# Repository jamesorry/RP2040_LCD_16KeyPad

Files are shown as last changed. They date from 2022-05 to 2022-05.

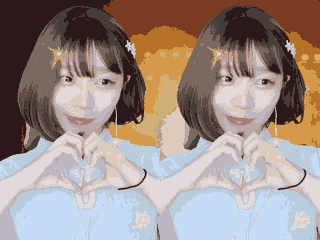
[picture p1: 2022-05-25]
firmware/images/697478.bmp

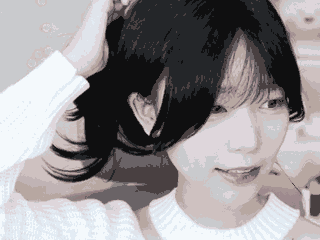
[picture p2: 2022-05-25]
firmware/images/LINE_ALBUM_2022517_220517_4.bmp

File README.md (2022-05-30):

# [RP2040_LCD_16KeyPad](https://hackmd.io/@Jub9Bu1BR0qRYeSAA0wUJQ/RP2040_LCD_16KeyPad)



## 元件
* 16 x Cherry MX 1u
* 16 x 1N4148 diodes
* 16 x RGB LEDs SK6812MINI-E([datasheet](https://www.google.com/url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))
* 1 x RP2040-zero([wiki](https://www.waveshare.net/wiki/RP2040-Zero))
* 1 x 2.4inch SPI ili9341 LCD module([wiki](http://www.lcdwiki.com/zh/2.4inch_SPI_Module_ILI9341_SKU:MSP2402))
* 1 x Rotary encoder switch

## Circuitpython 環境設定
### [官方教學文件](https://learn.adafruit.com/circuitpython-essentials)
### [API Reference](https://docs.circuitpython.org/en/latest/docs/index.html)
### [Library Bundle](https://github.com/adafruit/Adafruit_CircuitPython_Bundle/releases)
### [Community Library Bundle](https://github.com/adafruit/CircuitPython_Community_Bundle/releases)
### 燒綠官方韌體
1. [下載UF2](https://circuitpython.org/board/raspberry_pi_pico/)


2. 將板子按住BOOT键後連接電腦，鬆開BOOT鍵，電腦會出現一個新的磁碟空間，將下載的.uf2檔案複製進去即可完成燒錄。
### Thonny IDE
[官網下載](https://thonny.org/)
1. 下载Thonny IDE Windows版 並依照步驟安裝
2. 安裝完成後，第一次要配置語言和主板環境，為了使用Pico，所以注意主板環境選擇Raspberry Pi 選項。
3. 完成後，修改編譯環境，選擇CircuitPython，若已經接上設備，則可選擇連結埠



1. 點擊OK回到Thonny主界面，然后點擊停止按鈕，在Shell中即可顯示當前使用到的環境

以上都有出現即完成安裝設定

### 執行
將firmware資料夾的所有檔案複製進板子的磁碟空間內，完成後將板子重新啟動則可使用

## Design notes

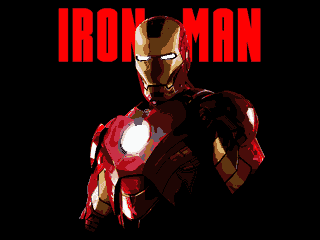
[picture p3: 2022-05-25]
firmware/images/_21_black-iron-man-wallpaper_Wallpaper-Iron-Man,-Artwork,-Minimal,-Low-poly,-Dark-.bmp

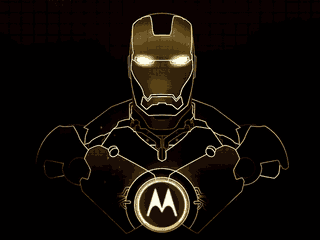
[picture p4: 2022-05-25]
firmware/images/_21_black-iron-man-wallpaper_Iron-Man-Wallpapers-Top-Free-Iron-Man-Backgrounds-.bmp

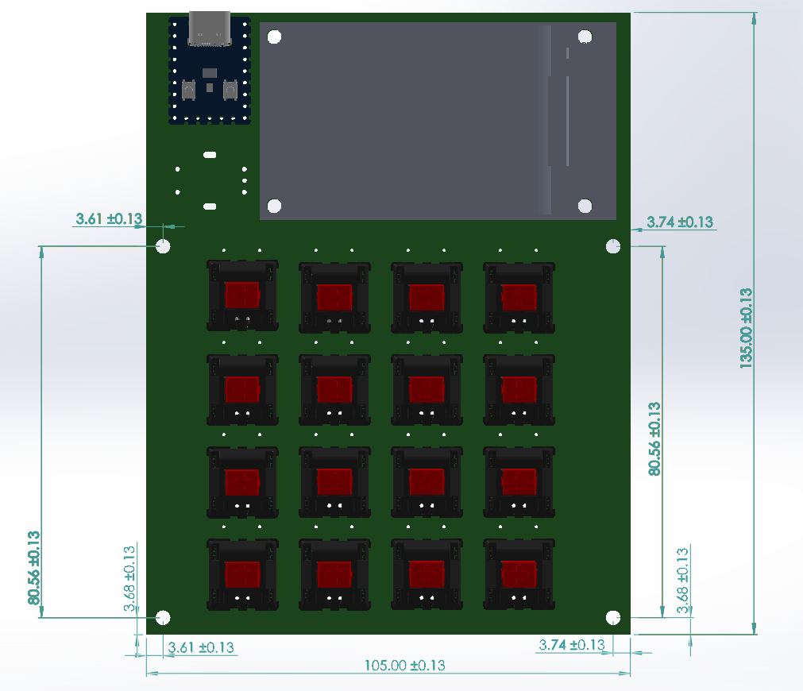
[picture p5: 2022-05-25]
PCB-design/Snipaste_2022-05-17_00-06-32.png

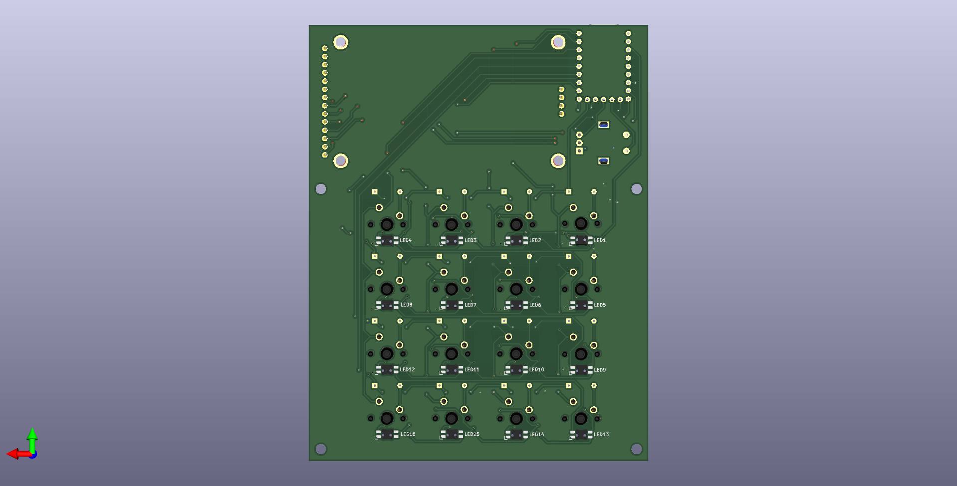
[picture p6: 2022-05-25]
images/RP2040_16Key_ili9341_LCD_keypad_back.png

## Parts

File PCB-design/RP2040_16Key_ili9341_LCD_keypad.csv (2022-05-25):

Source: | C:\Users\james\Desktop\LAB357\Raspberry Pi Pico\Pi Pico KeyPad\Pi Pico RP2040 keypad\RP2040_16Key_ili9341_LCD_keypad\RP2040_16Key_ili9341_LCD_keypad.kicad_sch
Date: | 2022/5/18
Tool: | Eeschema (6.0.4)
Generator: | C:\Program Files\KiCad\6.0\bin\scripting\plugins/bom_csv_grouped_by_value.py
Component Count: | 51
Individual Components:
Item | Qty | Reference(s) | Value | LibPart | Footprint | Datasheet
 |  | D1 | D | Device:D | keyboard_parts:D_SOD123_axial | ~
 |  | D2 | D | Device:D | keyboard_parts:D_SOD123_axial | ~
 |  | D3 | D | Device:D | keyboard_parts:D_SOD123_axial | ~
 |  | D4 | D | Device:D | keyboard_parts:D_SOD123_axial | ~
 |  | D5 | D | Device:D | keyboard_parts:D_SOD123_axial | ~
 |  | D6 | D | Device:D | keyboard_parts:D_SOD123_axial | ~
 |  | D7 | D | Device:D | keyboard_parts:D_SOD123_axial | ~
 |  | D8 | D | Device:D | keyboard_parts:D_SOD123_axial | ~
 |  | D9 | D | Device:D | keyboard_parts:D_SOD123_axial | ~
 |  | D10 | D | Device:D | keyboard_parts:D_SOD123_axial | ~
 |  | D11 | D | Device:D | keyboard_parts:D_SOD123_axial | ~
 |  | D12 | D | Device:D | keyboard_parts:D_SOD123_axial | ~
 |  | D13 | D | Device:D | keyboard_parts:D_SOD123_axial | ~
 |  | D14 | D | Device:D | keyboard_parts:D_SOD123_axial | ~
 |  | D15 | D | Device:D | keyboard_parts:D_SOD123_axial | ~
 |  | D16 | D | Device:D | keyboard_parts:D_SOD123_axial | ~
 |  | K1 | KEYSW | keyboard_parts:KEYSW | Button_Switch_Keyboard:SW_Cherry_MX_1.00u_PCB
 |  | K2 | KEYSW | keyboard_parts:KEYSW | Button_Switch_Keyboard:SW_Cherry_MX_1.00u_PCB
 |  | K3 | KEYSW | keyboard_parts:KEYSW | Button_Switch_Keyboard:SW_Cherry_MX_1.00u_PCB
 |  | K4 | KEYSW | keyboard_parts:KEYSW | Button_Switch_Keyboard:SW_Cherry_MX_1.00u_PCB
 |  | K5 | KEYSW | keyboard_parts:KEYSW | Button_Switch_Keyboard:SW_Cherry_MX_1.00u_PCB
 |  | K6 | KEYSW | keyboard_parts:KEYSW | Button_Switch_Keyboard:SW_Cherry_MX_1.00u_PCB
 |  | K7 | KEYSW | keyboard_parts:KEYSW | Button_Switch_Keyboard:SW_Cherry_MX_1.00u_PCB
 |  | K8 | KEYSW | keyboard_parts:KEYSW | Button_Switch_Keyboard:SW_Cherry_MX_1.00u_PCB
 |  | K9 | KEYSW | keyboard_parts:KEYSW | Button_Switch_Keyboard:SW_Cherry_MX_1.00u_PCB
 |  | K10 | KEYSW | keyboard_parts:KEYSW | Button_Switch_Keyboard:SW_Cherry_MX_1.00u_PCB
 |  | K11 | KEYSW | keyboard_parts:KEYSW | Button_Switch_Keyboard:SW_Cherry_MX_1.00u_PCB
 |  | K12 | KEYSW | keyboard_parts:KEYSW | Button_Switch_Keyboard:SW_Cherry_MX_1.00u_PCB
 |  | K13 | KEYSW | keyboard_parts:KEYSW | Button_Switch_Keyboard:SW_Cherry_MX_1.00u_PCB
 |  | K14 | KEYSW | keyboard_parts:KEYSW | Button_Switch_Keyboard:SW_Cherry_MX_1.00u_PCB
 |  | K15 | KEYSW | keyboard_parts:KEYSW | Button_Switch_Keyboard:SW_Cherry_MX_1.00u_PCB
 |  | K16 | KEYSW | keyboard_parts:KEYSW | Button_Switch_Keyboard:SW_Cherry_MX_1.00u_PCB
 |  | LED1 | MX_SK6812MINI-E | :MX_SK6812MINI-E_1 | marbastlib-mx:LED_MX_6028R
 |  | LED2 | MX_SK6812MINI-E | :MX_SK6812MINI-E_2 | marbastlib-mx:LED_MX_6028R
 |  | LED3 | MX_SK6812MINI-E | :MX_SK6812MINI-E_3 | marbastlib-mx:LED_MX_6028R
 |  | LED4 | MX_SK6812MINI-E | :MX_SK6812MINI-E_4 | marbastlib-mx:LED_MX_6028R
 |  | LED5 | MX_SK6812MINI-E | :MX_SK6812MINI-E_5 | marbastlib-mx:LED_MX_6028R
 |  | LED6 | MX_SK6812MINI-E | :MX_SK6812MINI-E_6 | marbastlib-mx:LED_MX_6028R
 |  | LED7 | MX_SK6812MINI-E | :MX_SK6812MINI-E_7 | marbastlib-mx:LED_MX_6028R
 |  | LED8 | MX_SK6812MINI-E | :MX_SK6812MINI-E_8 | marbastlib-mx:LED_MX_6028R
 |  | LED9 | MX_SK6812MINI-E | :MX_SK6812MINI-E_9 | marbastlib-mx:LED_MX_6028R
 |  | LED10 | MX_SK6812MINI-E | :MX_SK6812MINI-E_10 | marbastlib-mx:LED_MX_6028R
 |  | LED11 | MX_SK6812MINI-E | :MX_SK6812MINI-E_11 | marbastlib-mx:LED_MX_6028R
 |  | LED12 | MX_SK6812MINI-E | :MX_SK6812MINI-E_12 | marbastlib-mx:LED_MX_6028R
 |  | LED13 | MX_SK6812MINI-E | :MX_SK6812MINI-E_13 | marbastlib-mx:LED_MX_6028R
 |  | LED14 | MX_SK6812MINI-E | :MX_SK6812MINI-E_14 | marbastlib-mx:LED_MX_6028R
 |  | LED15 | MX_SK6812MINI-E | :MX_SK6812MINI-E_15 | marbastlib-mx:LED_MX_6028R
 |  | LED16 | MX_SK6812MINI-E | marbastlib-mx:MX_SK6812MINI-E | marbastlib-mx:LED_MX_6028R
 |  | RZ1 | RP2040-Zero | rp2040-zero:RP2040-Zero | RP2040-Zero:RP2040-Zero
 |  | SW1 | RotaryEncoder_Switch | Device:RotaryEncoder_Switch | Keebio-Parts:RotaryEncoder_Alps_EC11E-Switch_Vertical_H20mm | ~
 |  | U1 | 2.4_TFT_SPI_240x320 | 2.4inch_ili9341:2.4_TFT_SPI_240x320 | 2.4inch_ili9341:2.4_TFT_SPI_240x320 | http://www.lcdwiki.com/zh/2.4inch_SPI_Module_ILI9341_SKU:MSP2402

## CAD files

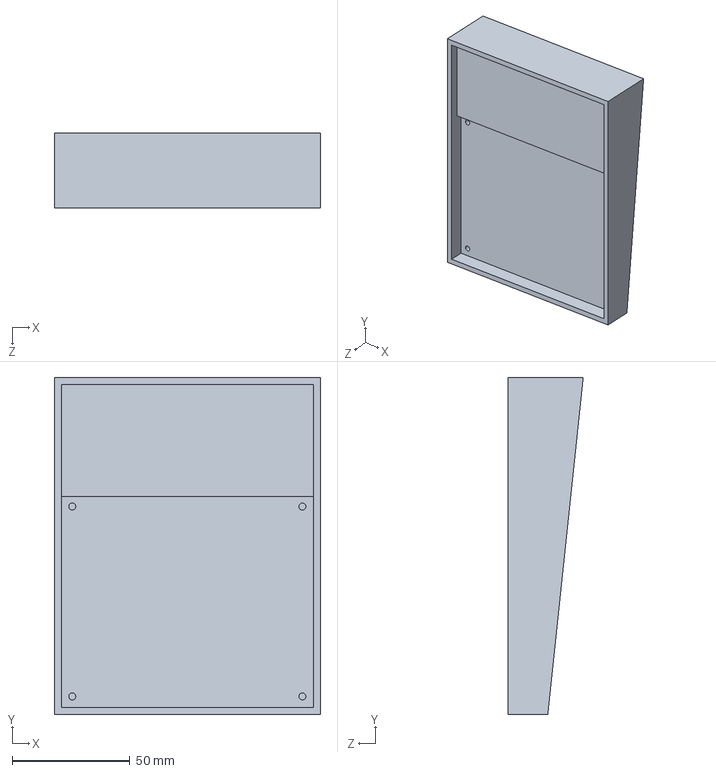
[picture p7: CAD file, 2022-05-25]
3DP-Bottom_Holder/Bottom_Holder.SLDPRT
113.0 x 143.0 x 32.0 mm

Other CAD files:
3DP-Bottom_Holder/Bottom_Holder.STL

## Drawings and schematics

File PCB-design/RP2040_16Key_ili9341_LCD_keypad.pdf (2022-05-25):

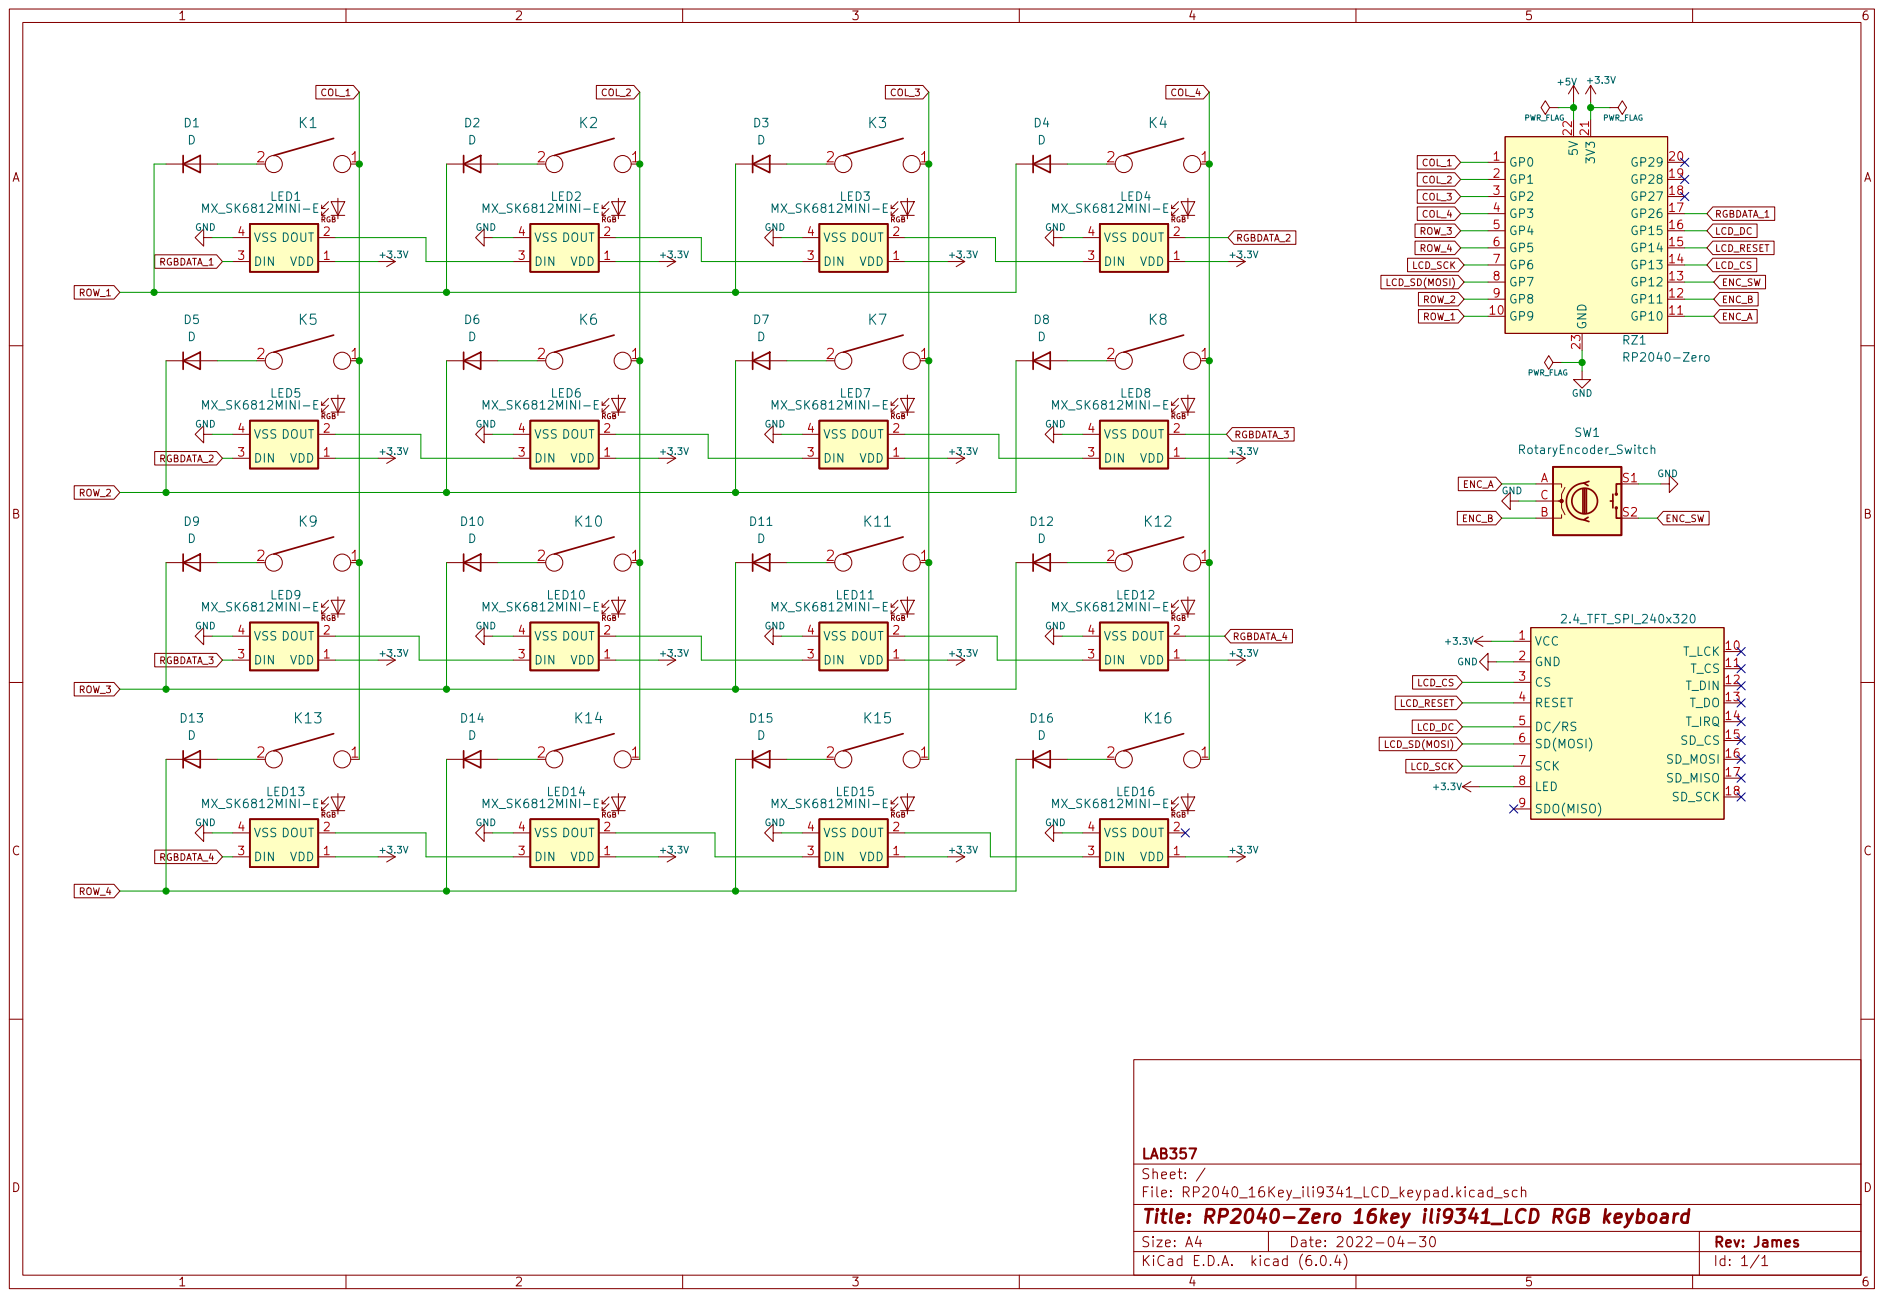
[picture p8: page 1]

Id: 1/1 Title: RP2040-Zero 16key ili9341_LCD RGB keyboard

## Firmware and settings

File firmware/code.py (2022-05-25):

import os
import time
import displayio
import terminalio
from adafruit_display_shapes.rect import Rect
from adafruit_display_text import label
from myMacroPad import MacroPad
import gc
import random
import adafruit_imageload

displayio.release_displays()
def DEBUG_STRING(string):
    pass
#     print(string)
def DEBUG_STRING_INFO(string, value):
    pass
#     print(string, value)
    
# CONFIGURABLES ------------------------

MACRO_FOLDER = '/macros'
KEY_TOTAL = 16
IMAGE_FOLDER = "/images"
change_press_RGB = True #when press btn change rgb color
now_RGB_animation_num = -1
start_picture_show = False #進入更新圖片迴圈(無法做其他事情)
break_flag = True #用來中斷迴圈
show_Information = False #進到此畫面
list_infomation = ['Version: 0.1.2',
                   'CircuitPython 7.2.5',
                   'RP2040-Zero',
                   '16key_SPI_ili9341_LCD',
                   '@James Lu']
# CLASSES AND FUNCTIONS ----------------
class App:
    """ Class representing a host-side application, for which we have a set
        of macro sequences. Project code was originally more complex and
        this was helpful, but maybe it's excessive now?"""
    def __init__(self, appdata):
        self.name = appdata['name']
        self.macros = appdata['macros']

    def switch(self):
        """ Activate application settings; update OLED labels and LED
            colors. """
        group[KEY_TOTAL + 1].text = self.name   # Application name
        DEBUG_STRING_INFO("self.name:", str(self.name))
        for i in range(KEY_TOTAL):
            if i < len(self.macros): # Key in use, set label + LED color
                if change_press_RGB:
                    macropad.pixels[i] = self.macros[i][0]
                group[i].text = self.macros[i][1]
            else:  # Key not in use, no label or LED
                if change_press_RGB:
                    macropad.pixels[i] = 0
                group[i].text = ''
        if self.name == "RGB Config":
            group[3].text = str(round(macropad.pixels.brightness,1))
            group[11].text = str(now_RGB_animation_num)
        macropad.keyboard.release_all()
        macropad.consumer_control.release()
        macropad.mouse.release_all()
        #if not macropad.animations.animate():
        if change_press_RGB:
            DEBUG_STRING("-----PAGE RGB-----")
            macropad.pixels.show()
        gc.collect()


# INITIALIZATION -----------------------

macropad = MacroPad()
macropad.pixels.auto_write = False
macropad.pixels.brightness = 0.1

# Set up displayio group with all the labels
group = displayio.Group()
DEBUG_STRING_INFO("width:", str(macropad.display.width))
DEBUG_STRING_INFO("height:", str(macropad.display.height))

for key_index in range(KEY_TOTAL):
    x = key_index % 4
    y = key_index // 4
    group.append(label.Label(terminalio.FONT, text='', color=0xFFFFFF,scale=2,
                             anchored_position=((macropad.display.width - 1) * x / 3,
                                                40+(macropad.display.height//5*(y+1))),
                             anchor_point=(x / 3, 1.0)))
    
group.append(Rect(0, 0, macropad.display.width, 40, fill=0xFFFFFF))
group.append(label.Label(terminalio.FONT, text='', color=0x000000,
                         scale=3,
                         anchored_position=(macropad.display.width / 2, -4),
                         anchor_point=(0.5, 0.0)))
macropad.display.show(group)

DEBUG_STRING_INFO("free mem@after bitmap", gc.mem_free())
gc.collect()
DEBUG_STRING_INFO("free mem@after gc.collect()", gc.mem_free())

# Load all the macro key setups from .py files in MACRO_FOLDER
apps = []
files = os.listdir(MACRO_FOLDER)
files.sort()
for filename in files:
    if filename.endswith('.py') and not filename.startswith('._'):
        try:
            module = __import__(MACRO_FOLDER + '/' + filename[:-3])
            apps.append(App(module.app))
        except (SyntaxError, ImportError, AttributeError, KeyError, NameError,
                IndexError, TypeError) as err:
            DEBUG_STRING_INFO("ERROR in", filename)
            import traceback
            traceback.print_exception(err, err, err.__traceback__)
            
images = []
image_files = os.listdir(IMAGE_FOLDER)
image_files.sort()
for filename in image_files:
    if filename.endswith('.bmp') and not filename.startswith('._'):
        try:
            image = IMAGE_FOLDER + '/' + filename
            images.append(image)
        except (SyntaxError, ImportError, AttributeError, KeyError, NameError,
                IndexError, TypeError) as err:
            DEBUG_STRING_INFO("ERROR in", filename)
            import traceback
            traceback.print_exception(err, err, err.__traceback__)
            
if not apps:
    group[KEY_TOTAL + 1].text = 'NO MACRO FILE'
    while True:
        pass

last_position = None
last_encoder_switch = macropad.encoder_switch_debounced.pressed
app_index = 0
apps[app_index].switch()
'''
# 'sequence' is an arbitrary-length list, each item is one of:
# Positive integer (e.g. Keycode.KEYPAD_MINUS): key pressed
# Negative integer: (absolute value) key released
# Float (e.g. 0.25): delay in seconds
# String (e.g. "Foo"): corresponding keys pressed & released
# List []: one or more Consumer Control codes (can also do float delay)
# Dict {}: mouse buttons/motion (might extend in future)

# Release any still-pressed keys, consumer codes, mouse buttons
# Keys and mouse buttons are individually released this way (rather
# than release_all()) because pad supports multi-key rollover, e.g.
# could have a meta key or right-mouse held down by one macro and
# press/release keys/buttons with others. Navigate popups, etc.
'''

# MAIN LOOP ----------------------------
DEBUG_STRING("---------Main Loop Start---------")
macropad.animations.freeze()

    
def Add_RGB_NUM():
    #global macropad
    global now_RGB_animation_num
    now_RGB_animation_num += 1
    if now_RGB_animation_num > macropad.total_animations_num-1:
        now_RGB_animation_num = 0
    group[11].text = str(now_RGB_animation_num)
    
def Sub_RGB_NUM():
    global now_RGB_animation_num
    now_RGB_animation_num -= 1
    if now_RGB_animation_num < -1:
        now_RGB_animation_num = macropad.total_animations_num-1
    group[11].text = str(now_RGB_animation_num)

while True:
    if start_picture_show == False:
        
        macropad.animations.animate()
        
        position = macropad.encoder
        if position != last_position:
            last_position = position
            DEBUG_STRING_INFO("encoder pos:", str(position))
            app_index = position % len(apps)
            DEBUG_STRING_INFO("app_index:", str(app_index))
            apps[app_index].switch()
            
        macropad.encoder_switch_debounced.update()
        encoder_switch = macropad.encoder_switch_debounced.pressed
        if encoder_switch != last_encoder_switch:
            last_encoder_switch = encoder_switch
            if len(apps[app_index].macros) < KEY_TOTAL+1:
                continue    # No 17th macro, just resume main loop
            key_number = KEY_TOTAL # else process below as 17th macro
            pressed = encoder_switch
        else:
            event = macropad.keys.events.get()
            if not event or event.key_number >= len(apps[app_index].macros):
                continue # No key events, or no corresponding macro, resume loop
            key_number = event.key_number
            pressed = event.pressed
            
        sequence = apps[app_index].macros[key_number][2]
        if pressed:
            if key_number < KEY_TOTAL: # No pixel for encoder button
                if change_press_RGB:
                    DEBUG_STRING("-----press RGB-----")
                    _r = random.randint(0, 255)
                    _g = random.randint(0, 255)
                    _b = random.randint(0, 255)
                    macropad.pixels[key_number] = (_r, _g, _b)
                    macropad.pixels.show()
                group[key_number].color = 0x000000
                group[key_number].background_color = 0xFFFFFF
            for item in sequence:
                DEBUG_STRING(str(item))
                if isinstance(item, int):
                    DEBUG_STRING("item is int")
                    if item >= 0:
                        macropad.keyboard.press(item)
                    else:
                        macropad.keyboard.release(-item)
                elif isinstance(item, float):
                    DEBUG_STRING("item is float")
                    time.sleep(item)
                elif isinstance(item, str):
                    DEBUG_STRING("item is str")
                    macropad.keyboard_layout.write(item)
                elif isinstance(item, list):
                    DEBUG_STRING("item is list")
                    for code in item:
                        if isinstance(code, int):
                            macropad.consumer_control.release()
                            macropad.consumer_control.press(code)
                        if isinstance(code, float):
                            time.sleep(code)
                elif isinstance(item, dict):
                    DEBUG_STRING("item is dict")
                    if 'buttons' in item:
                        if item['buttons'] >= 0:
                            macropad.mouse.press(item['buttons'])
                        else:
                            macropad.mouse.release(-item['buttons'])
                    elif 'RGB_Light' in item:
                        DEBUG_STRING_INFO("Light", item['RGB_Light'])
                        macropad.pixels.brightness += item['RGB_Light']
                        group[3].text = str(round(macropad.pixels.brightness,1))
                        DEBUG_STRING_INFO("now RGB_Light", macropad.pixels.brightness)
                    elif 'RGB_AT' in item:
                        DEBUG_STRING_INFO("RGB_AT", item['RGB_AT'])
                        if item['RGB_AT'] == 'on':
                            if change_press_RGB:
                                macropad.animations.fill(0)
                                macropad.animations.resume()
                                change_press_RGB = False
                                Add_RGB_NUM()
                        elif item['RGB_AT'] == 'off':
                            if not change_press_RGB:
                                macropad.animations.freeze()
                                macropad.animations.fill(0)
                                change_press_RGB = True
                                Sub_RGB_NUM()
                                apps[app_index].switch()
                        elif item['RGB_AT'] == 'next':
                            if not change_press_RGB:
                                macropad.animations.fill(0)
                                macropad.animations.next()
                                Add_RGB_NUM()
                    elif 'info' in item:
                        #macropad.display_image("images/Namin_1.bmp")
                        macropad.animations.fill(0)
                        start_picture_show = True
                        show_Information = True
                        gc.collect()
                    elif 'image' in item:
                        macropad.animations.fill(0)
                        image_show_time = item['image']
                        start_picture_show = True
                        show_Information = False
                        break_flag = False
                        gc.collect()
                    macropad.mouse.move(item['x'] if 'x' in item else 0,
                                        item['y'] if 'y' in item else 0,
                                        item['wheel'] if 'wheel' in item else 0)
        else:
            for item in sequence:
                if isinstance(item, int):
                    if item >= 0:
                        macropad.keyboard.release(item)
                elif isinstance(item, dict):
                    if 'buttons' in item:
                        if item['buttons'] >= 0:
                            macropad.mouse.release(item['buttons'])
            macropad.consumer_control.release()
            if key_number < KEY_TOTAL: # No pixel for encoder button
                if change_press_RGB:
                    DEBUG_STRING("-----release RGB-----")
                    macropad.pixels[key_number] = apps[app_index].macros[key_number][0]
                    macropad.pixels.show()
                group[key_number].color = 0xFFFFFF
                group[key_number].background_color = 0x000000
    
    if start_picture_show == True:
        if show_Information:
            DEBUG_STRING_INFO("list_infomation:",len(list_infomation))
            white_Rect = Rect(0, 0, macropad.display.width, macropad.display.height, fill=0x000000)
            group.append(white_Rect)
            info_1 = label.Label(terminalio.FONT, text=str(list_infomation[0]), color=0xFFFFFF,
                         scale=2,
                         anchored_position=(0, (macropad.display.height / 5)*0),
                         anchor_point=(0.0, 0.0))
            info_2 = label.Label(terminalio.FONT, text=str(list_infomation[1]), color=0xFFFFFF,
                         scale=2,
                         anchored_position=(0, (macropad.display.height / 5)*1),
                         anchor_point=(0.0, 0.0))
            info_3 = label.Label(terminalio.FONT, text=str(list_infomation[2]), color=0xFFFFFF,
                         scale=2,
                         anchored_position=(0, (macropad.display.height / 5)*2),
                         anchor_point=(0.0, 0.0))
            info_4 = label.Label(terminalio.FONT, text=str(list_infomation[3]), color=0xFFFFFF,
                         scale=2,
                         anchored_position=(0, (macropad.display.height / 5)*3),
                         anchor_point=(0.0, 0.0))
            info_5 = label.Label(terminalio.FONT, text=str(list_infomation[4]), color=0xFFFFFF,
                         scale=2,
                         anchored_position=(0, (macropad.display.height / 5)*4),
                         anchor_point=(0.0, 0.0))
            group.append(info_1)
            group.append(info_2)
            group.append(info_3)
            group.append(info_4)
            group.append(info_5)
            while True:
                macropad.encoder_switch_debounced.update()
                encoder_switch = macropad.encoder_switch_debounced.pressed
                if encoder_switch != last_encoder_switch:
                    last_encoder_switch = encoder_switch
                    start_picture_show = False
                    show_Information = False
                    group.remove(white_Rect)
                    group.remove(info_1)
                    group.remove(info_2)
                    group.remove(info_3)
                    group.remove(info_4)
                    group.remove(info_5)
                    break
        else:
            white_Rect = Rect(0, 0, macropad.display.width, macropad.display.height, fill=0xFFFFFF)
            group.append(white_Rect)
            while True:
                for bmpfile in images:
                    DEBUG_STRING("========================")
                    
                    DEBUG_STRING_INFO("bitmap file:", bmpfile)
                    
                    DEBUG_STRING_INFO("free mem@before bitmap", gc.mem_free())
                    
                    background = displayio.OnDiskBitmap(bmpfile)
                    tile_grid = displayio.TileGrid(
                        background,
                        pixel_shader=background.pixel_shader,
                    )
                    
                    DEBUG_STRING_INFO("free mem@after bitmap", gc.mem_free())
                    gc.collect()
                    DEBUG_STRING_INFO("free mem@after gc.collect()", gc.mem_free())

                    # Add the TileGrid to the Group
                    group.append(tile_grid)
                    DEBUG_STRING_INFO("index: ", group.index(tile_grid))
                    # Add the Group to the Display
                    macropad.display.show(group)
                    time.sleep(image_show_time)
                    group.remove(tile_grid)
                    
                    macropad.encoder_switch_debounced.update()
                    encoder_switch = macropad.encoder_switch_debounced.pressed
                    if encoder_switch != last_encoder_switch:
                        last_encoder_switch = encoder_switch
                        start_picture_show = False
                        break_flag = True
                        break
                if break_flag:
                    group.remove(white_Rect)
                    macropad.display.refresh()
                    break
DEBUG_STRING("-bye-")

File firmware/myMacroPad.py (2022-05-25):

"""
A helper library for the Adafruit MacroPad RP2040.
  https://github.com/adafruit/Adafruit_CircuitPython_MacroPad

* Origin Author(s): Kattni Rembor
* Modify by: James Lu

**Hardware:**

* `Adafruit MacroPad RP2040 Bare Bones <https://www.adafruit.com/product/5100>`_
* `Adafruit MacroPad RP2040 Starter Kit <https://www.adafruit.com/product/5128>`_

**Software and Dependencies:**

* Adafruit CircuitPython firmware for the supported boards:
  https://circuitpython.org/downloads


* Adafruit's CircuitPython NeoPixel library:
  https://github.com/adafruit/Adafruit_CircuitPython_NeoPixel

* Adafruit's CircuitPython HID library:
  https://github.com/adafruit/Adafruit_CircuitPython_HID

* Adafruit's CircuitPython Display Text library:
  https://github.com/adafruit/Adafruit_CircuitPython_Display_Text

* Adafruit's CircuitPython Simple Text Display library:
  https://github.com/adafruit/Adafruit_CircuitPython_Simple_Text_Display

* Adafruit's CircuitPython Debouncer library:
  https://github.com/adafruit/Adafruit_CircuitPython_Debouncer

* Adafruit's CircuitPython Ticks library
  https://github.com/adafruit/Adafruit_CircuitPython_Ticks

"""
import array
import math
import time
import board
import digitalio
import rotaryio
import keypad
import neopixel
import displayio
import busio
import usb_hid
from adafruit_hid.keyboard import Keyboard
from adafruit_hid.keyboard_layout_base import KeyboardLayoutBase
from adafruit_hid.keyboard_layout_us import KeyboardLayoutUS
from adafruit_hid.keycode import Keycode
from adafruit_hid.consumer_control import ConsumerControl
from adafruit_hid.consumer_control_code import ConsumerControlCode
from adafruit_hid.mouse import Mouse
from adafruit_debouncer import Debouncer
import adafruit_ili9341
from adafruit_led_animation.animation.blink import Blink
from adafruit_led_animation.animation.sparklepulse import SparklePulse
from adafruit_led_animation.animation.comet import Comet
from adafruit_led_animation.animation.chase import Chase
from adafruit_led_animation.animation.pulse import Pulse
from adafruit_led_animation.animation.sparkle import Sparkle
from adafruit_led_animation.animation.rainbowchase import RainbowChase
from adafruit_led_animation.animation.rainbowsparkle import RainbowSparkle
from adafruit_led_animation.animation.rainbowcomet import RainbowComet
from adafruit_led_animation.animation.solid import Solid
from adafruit_led_animation.animation.colorcycle import ColorCycle
from adafruit_led_animation.animation.rainbow import Rainbow
from adafruit_led_animation.animation.customcolorchase import CustomColorChase
from adafruit_led_animation.sequence import AnimationSequence
from adafruit_led_animation.color import *
from adafruit_led_animation import helper

try:
    from neopixel import NeoPixel
    from keypad import Keys
    import adafruit_hid
except ImportError:
    pass

__version__ = "1.0.1"
__repo__ = "https://github.com/jamesorry/RP2040_LCD_16KeyPad.git"

ROTATED_KEYMAP_0 = (0, 1, 2, 3, 4, 5, 6, 7, 8, 9, 10, 11, 12, 13, 14, 15)
ROTATED_KEYMAP_90 = (3, 7, 11, 15, 2, 6, 10, 14, 1, 5, 9, 13, 0, 4, 8, 12)
ROTATED_KEYMAP_180 = (15, 14, 13, 12, 11, 10, 9, 8, 7, 6, 5, 4, 3, 2, 1, 0)
ROTATED_KEYMAP_270 = (12, 8, 4, 0, 13, 9, 5, 1, 14, 10, 6, 2, 15, 11, 7, 3)


keycodes = Keycode
"""Module level Keycode class, to be changed when initing Macropad with a different language"""

class _PixelMapLite:
    """Generate a pixel map based on a specified order. Designed to work with a set of 15 pixels,
    e.g. the MacroPad keypad LEDs.

    :param pixels: The pixel object.
    :param tuple order: The specified order of the pixels. Pixels are numbered 0-15. Defaults to
                        numerical order, ``0`` to ``15``.
    """

    def __init__(
        self,
        pixels: NeoPixel,
        order: Tuple[
            int, int, int, int, int, int, int, int, int, int, int, int, int, int, int, int
        ] = ROTATED_KEYMAP_0,
    ):
        self._pixels = pixels
        self._order = order
        self._num_pixels = len(pixels)
        self.fill = pixels.fill
        self.show = pixels.show
        self.n = self._num_pixels

    def __setitem__(self, index: int, val: int) -> None:
        if isinstance(index, slice):
            for val_i, in_i in enumerate(range(*index.indices(self._num_pixels))):
                self._pixels[self._order[in_i]] = val[val_i]
        else:
            self._pixels[self._order[index]] = val

    def __getitem__(self, index: int) -> int:
        if isinstance(index, slice):
            return [
                self._pixels[self._order[idx]]
                for idx in range(*index.indices(self._num_pixels))
            ]
        if index < 0:
            index += self._num_pixels
        if index >= self._num_pixels or index < 0:
            raise IndexError
        return self._pixels[self._order[index]]

    def __repr__(self) -> str:
        return self._pixels.__repr__()

    def __len__(self) -> int:
        return len(self._pixels)

    @property
    def auto_write(self) -> bool:
        """
        True if the neopixels should immediately change when set. If False, ``show`` must be
        called explicitly.
        """
        return self._pixels.auto_write

    @auto_write.setter
    def auto_write(self, value: bool) -> None:
        self._pixels.auto_write = value

    @property
    def brightness(self) -> float:
        """Overall brightness of the pixel (0 to 1.0)."""
        return self._pixels.brightness

    @brightness.setter
    def brightness(self, value: float) -> None:
        self._pixels.brightness = value
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
